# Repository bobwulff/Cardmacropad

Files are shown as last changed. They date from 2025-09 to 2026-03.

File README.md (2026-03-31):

# Cardmacropad
If you're reading this, I probably handed you a business card at some point. Oh it was so nice to meet you probably! Lets turn that business card into something useful, like a keyboard macropad.
<br><br>


You can also purchase [your own PCB here if you'd like](https://www.pcbway.com/project/shareproject/Macro_Pad_Card_999fac36.html)
<br><br>

# COMPONENTS REQUIRED:
| Component | Recommended Link | Alt Link |
| --- | --- | --- |
| RP2040 Zero | [Aliexpress](https://s.click.aliexpress.com/e/_okoF943) | [Amazon](https://amzn.to/3ZdtdvE) |
| 6x6x4.3 Tactile Push Button Switches | [Aliexpress](https://s.click.aliexpress.com/e/_oEwUhSf) | [Amazon](https://amzn.to/3GMue7G) |
| Kailh Low Profile Choc Switches | [Aliexpress](https://s.click.aliexpress.com/e/_onZQ1ER) | [Amazon](https://amzn.to/3ZcWPtb) |



# OPTIONAL:
| Component | Recommended Link | Alt Link |
| --- | --- | --- |
| Kailh Low Profile Hot-swappable PCB Socket | [Aliexpress](https://s.click.aliexpress.com/e/_oFkTKZv) | [Amazon](https://amzn.to/44trzcY) |
| Low Profile Keycaps | [Aliexpress](https://s.click.aliexpress.com/e/_oorbBj1) | [Amazon](https://amzn.to/42BwSVh) | 





# GET YOUR TOOLS READY

• USB-C cable <br>
• Soldering Iron <br>
• Solder <br>
• A safe surface to solder on <br>



# START THE ASSEMBLY

1) Place the PI-Zero flat onto the PCB and solder two of the corners for stability. When soldering, I would recommend melting the solder onto the exposed contact on the PCB, then dragging it onto the PI-Zero's contacts with the soldering iron <br><br>


2) Solder the rest of the PI-Zero's contacts onto the board <br><br>


3) Place the tact switches through the holes on the board <br><br>


4) Flip the board around and bend the pins of the switches so they are flat and stay in place (it helps to use a flat metal tool, or a coin) <br><br>


5) Solder the tact switches from the back (dont be afraid to glob that solder on and through the hole) <br><br>


6) Deside whether or not youre going to use hotswap sockets or just solder the switches in place <br><br>


7) If soldering the switches in place, just pop those suckers in. Make sure the metal pins of the switches are through the small silver holes <br><br>





8) Flip the board over and solder the metal pins on the back (GLOB IT ON). Do NOT solder the plastic nubs (seen in red here) <br><br>


# Congrats! You have completed the assembly


# NOW FOR THE FIRMWARE

1) Connect the macropad to a computer with a USB-C cable WHILE HOLDING the BOOT button on the PI-Zero. <br><br>


2) If done correctly, it will show up as a drive on your computer. If this does not happen, hold the BOOT button, and while holding the BOOT button press the RESET button one time. <br><br>


3) Drag over the [GP2040-CE_0.7.11_WaveshareZero.uf2 firmware linked here](https://github.com/bobwulff/Cardmacropad/blob/ba1f3849e7113883848c1dc979786deaaa10a982/GP2040-CE_0.7.11_WaveshareZero.uf2) <br><br>


4) Allow the device to completely reboot. To test if this worked, head over to [gamepadtester](https://hardwaretester.com/gamepad) and press some buttons <br><br>


# Congrats, you now have an X-input controller. But lets make it a keyboard.

1) Hold the SW5 button (bottom right tact switch) and press the RESET button one time. <br><br>


2) Next, head to http://192.168.7.1 in a web browser <br><br>


3) Click CONFIGURATION > Data Backup and Restoration <br><br>


4) Load [WDnumpad_ZERO.gp2040 found here](https://github.com/bobwulff/Cardmacropad/blob/ba1f3849e7113883848c1dc979786deaaa10a982/WDnumpad_ZERO.gp2040) <br><br>


5) Look at the top right corner of the web-page and change this dropdown to GENERIC <br><br>


6) Head to SETTINGS > INPUT MODE > and change inputs 1-10 to be your desired buttons. Below is an example of what I have mine set to. When you're done, make sure to click SAVE at the bottom and then REBOOT in the top right corner. <br><br>


7) Here is a map of what each button will be labeled as in the GP2040 keyboard mapping page (you want to look at the GENERIC column). Feel free to map each button to whatever you'd like <br><br>


8) If at this point you run into any issues, head over to the "GPIO Pin Mapping" page and click "GPIO Pin viewer" to see if the buttons work and what they are currently mapped to. You can also use this page to re-map them if need be.

# SUCCESS!!! You now have a MACROPAD!

3D printable case files [available here](https://github.com/bobwulff/Cardmacropad/tree/16b7419801c9fb5cbdbb282ee85d4b39a7bb93ee/3D%20Printable%20Case) <br>
<br>
| Component | Link |
| --- | ---
| Heat Threaded Inserts | [Amazon](https://amzn.to/3Rn92r1) |
| M2x6 screws | [Amazon](https://amzn.to/3GeJXMA) |
<br>


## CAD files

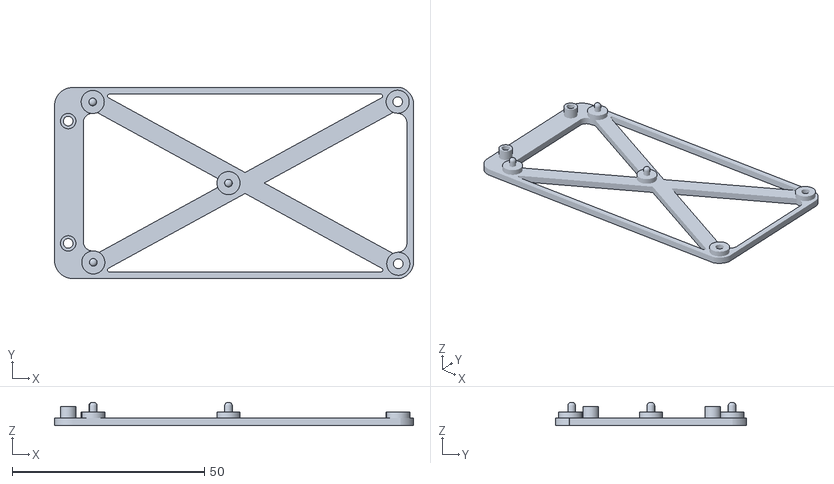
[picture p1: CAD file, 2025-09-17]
3D Printable Case/Base_Under_PCB.stl
93.3 x 49.7 x 6.10

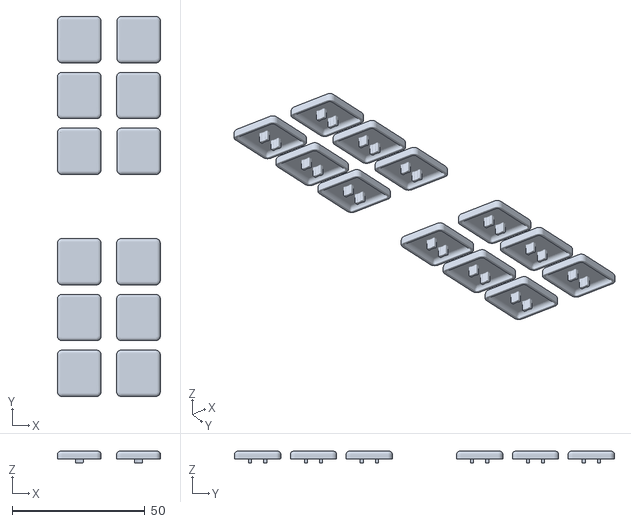
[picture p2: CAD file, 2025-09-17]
3D Printable Case/OPTIONAL_graphic_keycaps.stl
38.8 x 143.0 x 4.41

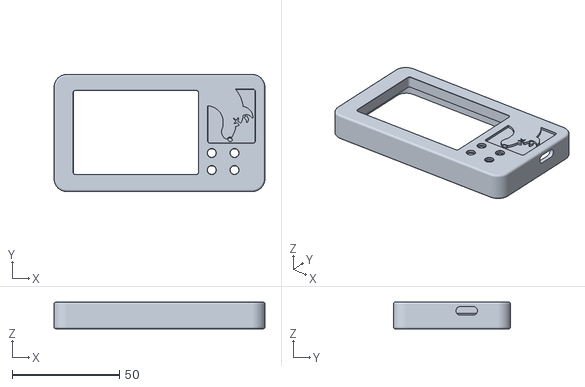
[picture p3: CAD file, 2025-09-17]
3D Printable Case/Top_Case.stl
98.3 x 54.6 x 12.5

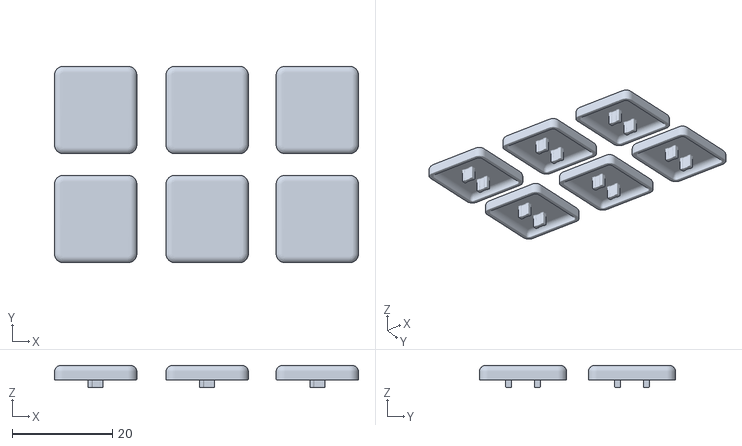
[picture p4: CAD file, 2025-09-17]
3D Printable Case/Blank_Keycaps.stl
60.7 x 39.2 x 4.41

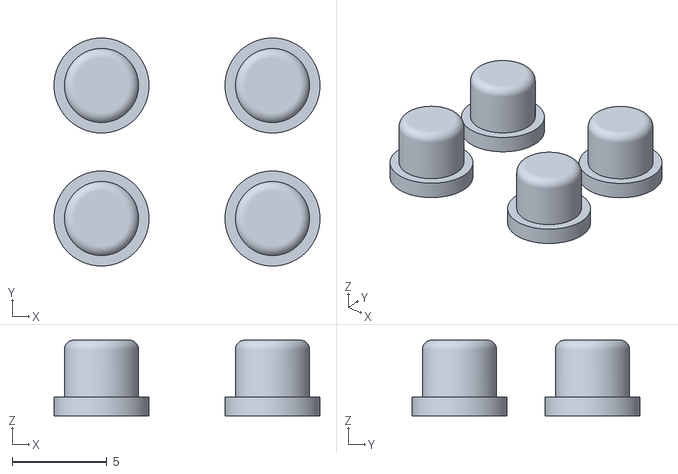
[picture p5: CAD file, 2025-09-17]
3D Printable Case/buttons.stl
14.0 x 12.0 x 4.00
